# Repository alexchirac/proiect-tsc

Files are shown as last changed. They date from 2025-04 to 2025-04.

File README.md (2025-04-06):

## © Copyright Chirac Alexandru-Stefan 333CA

# Hardware Overview and Component Specifications

This document outlines the key hardware components used in the system, including their roles and detailed specifications.

---

## 📑 Table of Contents

- [Main Controller](#main-controller)
- [Display System](#display-system)
- [Power](#power)
- [Memory and Storage](#memory-and-storage)
- [Sensors](#sensors)
- [Connectivity](#connectivity)
- [Block diagram](#block-diagram)
- [Pin Assignments](#pin-assignments)
- [Bill of Materials](#bill-of-materials)

---

## Main Controller

### ESP32-C6-WROOM-1-N8
- **Function**: Core microcontroller that manages all system operations.

---

## Display System

### E-Paper Display
- **Drive Circuit**: Custom electronics for controlling the display.
- **Display Type Selector**: Configurable support for different e-paper types.

---

## Power

### LDO Voltage Regulator — XC6220A331MR-G
- **Function**: Supplies regulated 3.3V to the system.
- **Input Voltage**: Up to 6.0 V
- **Output Current**: Up to 700 mA

### Battery Charger — MCP73831
- **Function**: Manages Li-Po battery charging.
- **Charge Current**: Up to 500 mA (programmable)
- **Charge Voltage**: Fixed at 4.2 V
- **Input Voltage**: Typically 5 V (USB)
- **Features**: Thermal protection, automatic termination, LED status indicator

### Battery Fuel Gauge — MAX17048G+T10
- **Function**: Monitors battery state-of-charge and voltage.
- **Interface**: I2C
- **Voltage Accuracy**: ±7.5 mV
- **Current Consumption**: ~23 µA

### Supercapacitor — CPH3225A
- **Function**: Provides short-term backup power during power loss.

### Diode — MBR0530
- **Function**: Reverse voltage protection and efficient switching.
- **Max Current**: 0.5 A
- **Forward Voltage**: ~0.3–0.4 V

---

## Memory and Storage

### External NOR Flash — W25Q512JVEIQ
- **Function**: High-capacity external storage.
- **Capacity**: 512 Mbit (64 MB)
- **Interface**: SPI
- **Voltage**: 3.3 V
- **Usage**: Firmware, configuration data, graphical assets

### SD Card Slot
- **Function**: Expandable storage option for user or application data.

---

## Sensors

### Environmental Sensor — BME688
- **Function**: Measures environmental data.
- **Measurements**: Temperature, Humidity, Pressure, VOC gas
- **Interface**: I2C
- **Operating Voltage**: 1.7 V – 3.6 V

### RTC Module — DS3231SN
- **Function**: Maintains accurate timekeeping.
- **Accuracy**: ±2 ppm (~1 minute/year)
- **Interface**: I2C
- **Voltage**: 2.3 V – 5.5 V
- **Feature**: Integrated battery backup

---

## Connectivity

### USB-C Connector
- **Function**: Provides both power input and data communication.

### ESD Protection — USBLC6-2SC6Y
- **Function**: Protects USB lines from electrostatic discharge.

### Qwiic/Stemma QT Connector
- **Function**: Supports I2C-based expansion modules.

---

## Block Diagram

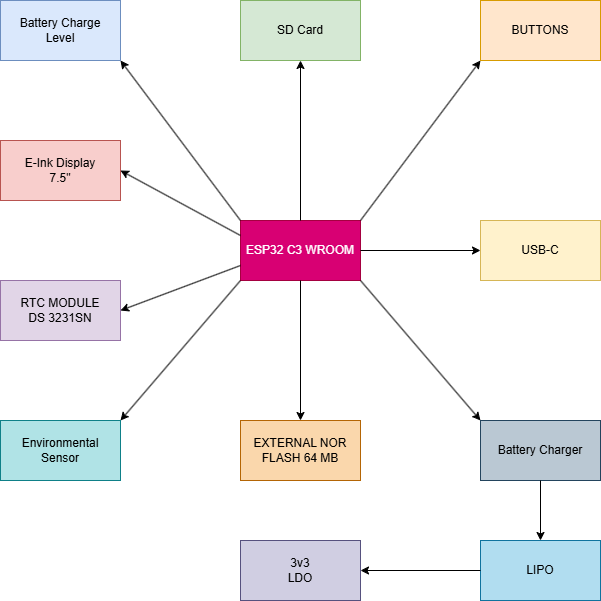
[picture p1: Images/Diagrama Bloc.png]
Block Diagram


---

## Pin Assignments

| ESP32-C6 Pin | Function | Connected To | Description |
|---|---|---|---|
| 3 | RESET | Reset Button | System hardware reset |
| 4 | SS_SD | SD Card (pin 2) | SPI Slave Select for SD card |
| 6 | SCK | SD Card (pin 5) | SPI Clock signal |
| 7 | MOSI | SD Card (pin 3) | SPI Master Out Slave In |
| 8 | INT_RTC | RTC Module (pin 3) | Interrupt signal from RTC |
| 9 | 32KHz | RTC Module (pin 1) | 32KHz clock signal from RTC |
| 13 | USB_D- | USB-C Connector (pin 3) | USB Data Negative line |
| 14 | USB_D+ | USB-C Connector (pin 1) | USB Data Positive line |
| 15 | IO/BOOT | Boot Button | Boot mode selector button |
| 16 | RTC_RST | RTC Module (pin 4) | RTC reset control |
| 17 | I2C_PW | BME688 Sensor (pins 6, 8, 2)| Power control for environmental sensor|
| 19 | SDA | Multiple I²C devices | I²C Serial Data line (shared) |
| 20 | SCL | Multiple I²C devices | I²C Serial Clock line (shared) |
| 23 | IO/CHANGE | Change Button | Display/Mode change button |
| 27 | MISO | SD Card (pin 7) | SPI Master In Slave Out |

---

## Bill of Materials

 | Device | Qty | PURCHASE-URL |
 |--------|-----|--------------|
 | ADAFRUIT_LEDCHIP-LED0603 | 1 | https://www.snapeda.com/parts/KP-1608SURCK/Kingbright/view-part/?ref=search&t=LED%200603 | 
 | EAGLE-LTSPICE_CC0402 | 1 | https://componentsearchengine.com/part-view/CC0402MRX5R5BB106/YAGEO | 
 | RCL_CPOL-EUCT3528 | 1 | https://a360.co/4iZy6AA | 
 | SJ | 1 | https://grabcad.com/library/solder-jumpers-1 | 
 | VARISTOR_3216 | 1 | https://www.mouser.co.uk/ProductDetail/EPCOS-TDK/B72520T0350K062?qs=dEfas%2FXlABIszF52uu7vrg%3D%3D | 
 | EAGLE-LTSPICE_CC0402 | 1 | https://componentsearchengine.com/part-view/CC0402MRX5R5BB106/YAGEO | 
 | ESP32_WROVER_EAGLE-LTSPICE_RR0402 | 1 | https://componentsearchengine.com/part-view/R0402%201%25%20100%20K%20(RC0402FR-07100KL)/YAGEO | 
 | EAGLE-LTSPICE_CC0402 | 1 | https://componentsearchengine.com/part-view/CC0402MRX5R5BB106/YAGEO | 
 | ESP32_WROVER_EAGLE-LTSPICE_RR0402 | 1 | https://componentsearchengine.com/part-view/R0402%201%25%20100%20K%20(RC0402FR-07100KL)/YAGEO | 
 | EAGLE-LTSPICE_CC0402 | 7 | https://componentsearchengine.com/part-view/CC0402MRX5R5BB106/YAGEO | 
 | ESP32_WROVER_EAGLE-LTSPICE_RR0402 | 16 | https://componentsearchengine.com/part-view/R0402%201%%20100%20K%20(RC0402FR-07100KL)/YAGEO | 
 | EAGLE-LTSPICE_CC0402 | 1 | https://componentsearchengine.com/part-view/CC0402MRX5R5BB106/YAGEO | 
 | 112A-TAAR-R03_ATTEND | 1 | https://store.comet.srl.ro/Catalogue/Product/43497/ | 
 | ESP32_WROVER_EAGLE-LTSPICE_RR0402 | 1 | https://componentsearchengine.com/part-view/R0402%201%25%20100%20K%20(RC0402FR-07100KL)/YAGEO | 
 | EAGLE-LTSPICE_CC0402 | 1 | https://componentsearchengine.com/part-view/CC0402MRX5R5BB106/YAGEO | 
 | EAGLE-LTSPICE_CC0402 | 8 | https://componentsearchengine.com/part-view/CC0402MRX5R5BB106/YAGEO | 
 | EAGLE-LTSPICE_CC0402 | 1 | https://componentsearchengine.com/part-view/CC0402MRX5R5BB106/YAGEO | 
 | ESP32_WROVER_EAGLE-LTSPICE_RR0402 | 1 | https://componentsearchengine.com/part-view/R0402%201%25%20100%20K%20(RC0402FR-07100KL)/YAGEO | 
 | ESP32_WROVER_EAGLE-LTSPICE_RR0402 | 1 | https://componentsearchengine.com/part-view/R0402%201%25%20100%20K%20(RC0402FR-07100KL)/YAGEO | 
 | ESP32_WROVER_SPARKFUN-DISCRETESEMI_MOSFET_PCH-DMG2305UX-7 | 2 | https://componentsearchengine.com/part-view/SI1308EDL-T1-GE3/Vishay | 
 | ESP32_WROVER_EAGLE-LTSPICE_RR0402 | 1 | https://componentsearchengine.com/part-view/R0402%201%25%20100%20K%20(RC0402FR-07100KL)/YAGEO | 
 | EAGLE-LTSPICE_CC0402 | 1 | https://componentsearchengine.com/part-view/CC0402MRX5R5BB106/YAGEO | 
 | EAGLE-LTSPICE_CC0402 | 3 | https://componentsearchengine.com/part-view/CC0402MRX5R5BB106/YAGEO | 
 | EAGLE-LTSPICE_CC0402 | 1 | https://componentsearchengine.com/part-view/CC0402MRX5R5BB106/YAGEO | 
 | ESP32_WROVER_EAGLE-LTSPICE_RR0402 | 2 | https://componentsearchengine.com/part-view/R0402%201%25%20100%20K%20(RC0402FR-07100KL)/YAGEO | 
 | 744043680IND_4828-WE-TPC_WRE | 1 | https://eu.mouser.com/ProductDetail/Wurth-Elektronik/744043680?qs=PGXP4M47uW6VkZq%252BkzjrHA%3D%3D | 
 | BD5229G-TR | 1 | https://componentsearchengine.com/part-view/BD5229G-TR/ROHM%20Semiconductor | 
 | BUTTON_CUSYOMV1PACKAGE | 3 | https://www.snapeda.com/parts/EVQP7L01P/Panasonic/view-part/?ref=search&t=evqp7l | 
 | CPH3225A | 1 | https://www.snapeda.com/api/url_track_click_mouser/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 | 
 | DS3231SN# | 1 | https://www.snapeda.com/api/url_track_click_mouser/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 | 
 | ESP32-C6-WROOM-1-N8 | 1 | https://www.snapeda.com/parts/ESP32-C6-WROOM-1-N8/Espressif+Systems/view-part/?ref=eda | 
 | ESP32_WROVER_AVX---SD0805S020S1R0_AVX_ SD0805S020S1R0_0_0AVX_SD0805S020S1R0_0_0 | 2 | https://eu.mouser.com/ProductDetail/KYOCERA-AVX/SD0805S020S1R0?qs=jCA%252BPfw4LHbpkAoSnwrdjw%3D%3D | 
 | ESP32_WROVER_BME680_BME680 | 1 | https://www.snapeda.com/parts/BME680/Bosch/view-part/?welcome=home | 
 | ESP32_WROVER_SPARKFUN-IC-POWER_MCP73831 | 1 | https://www.digikey.ro/en/products/detail/microchip-technology/MCP73831T-2ACI-OT/964301 | 
 | FH34SRJ-24S-0.5SH_99_ | 1 | https://componentsearchengine.com/part-view/XC6220A331MR-G/Torex | 
 | MAX17048G+T10 | 1 | https://www.snapeda.com/api/url_track_click_mouser/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 | 
 | MBR0530 | 3 | https://www.snapeda.com/api/url_track_click_mouser/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 | 
 | PGB1010603MR | 6 | https://www.snapeda.com/api/url_track_click_mouser/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 | 
 | QWIIC_CONNECTORJS-1MM | 1 | https://www.digikey.ro/en/models/926710 | 
 | SAMACSYS_PARTS_USB4110-GF-A | 1 | https://componentsearchengine.com/part-view/USB4110-GF-A/GCT%20(GLOBAL%20CONNECTOR%20TECHNOLOGY) | 
 | SI1308EDL-T1-GE3 | 1 | https://componentsearchengine.com/part-view/SI1308EDL-T1-GE3/Vishay | 
 | TPTP20R | 17 | https://grabcad.com/library/test-points-printed-circuit-board-1 | 
 | USBLC6-2SC6Y | 1 | https://www.snapeda.com/parts/USBLC6-2SC6Y/STMicroelectronics/view-part/?ref=eda | 
 | W25Q512JVEIQ | 1 | https://www.snapeda.com/parts/W25Q512JVEIQ/Winbond+Electronics/view-part/?ref=eda |

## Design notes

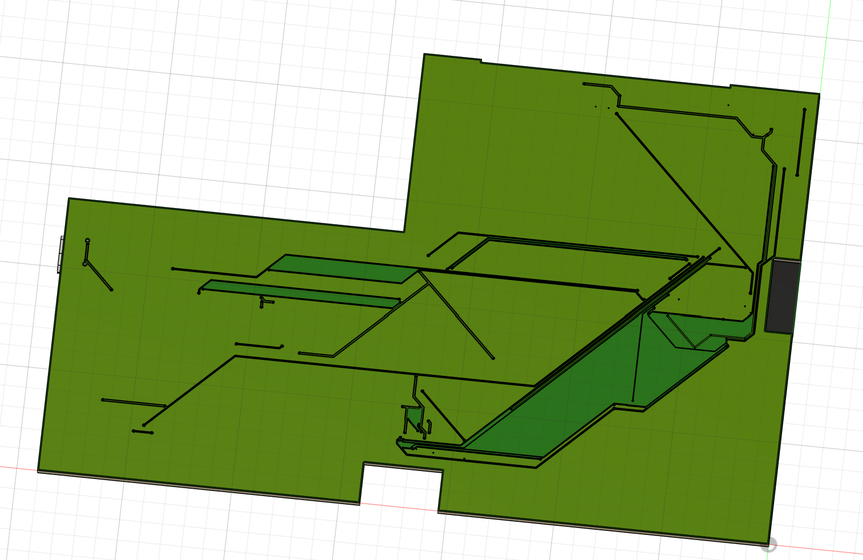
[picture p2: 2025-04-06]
Images/Board Back.png

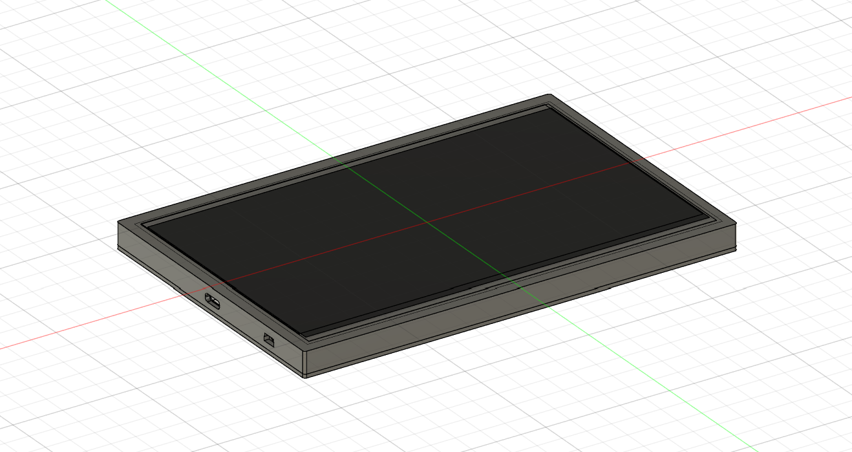
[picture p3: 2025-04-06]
Images/Device Top.png

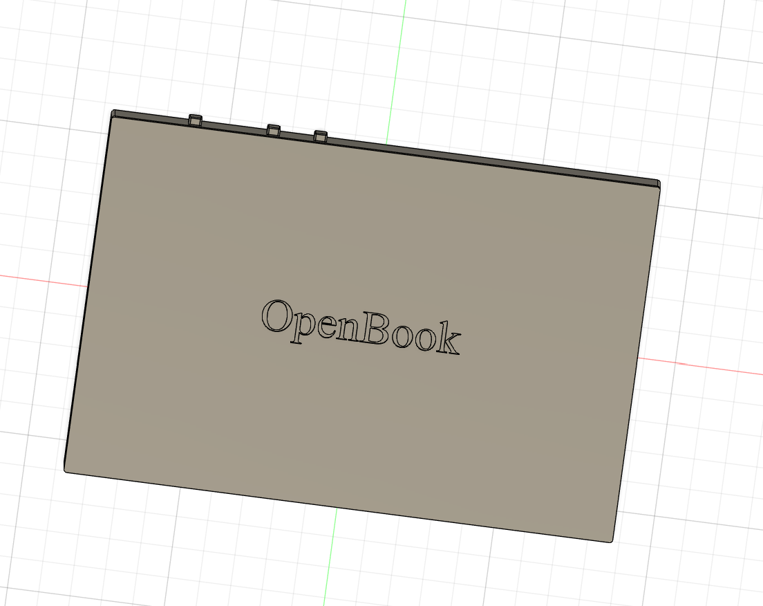
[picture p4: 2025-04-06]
Images/Device Back.png

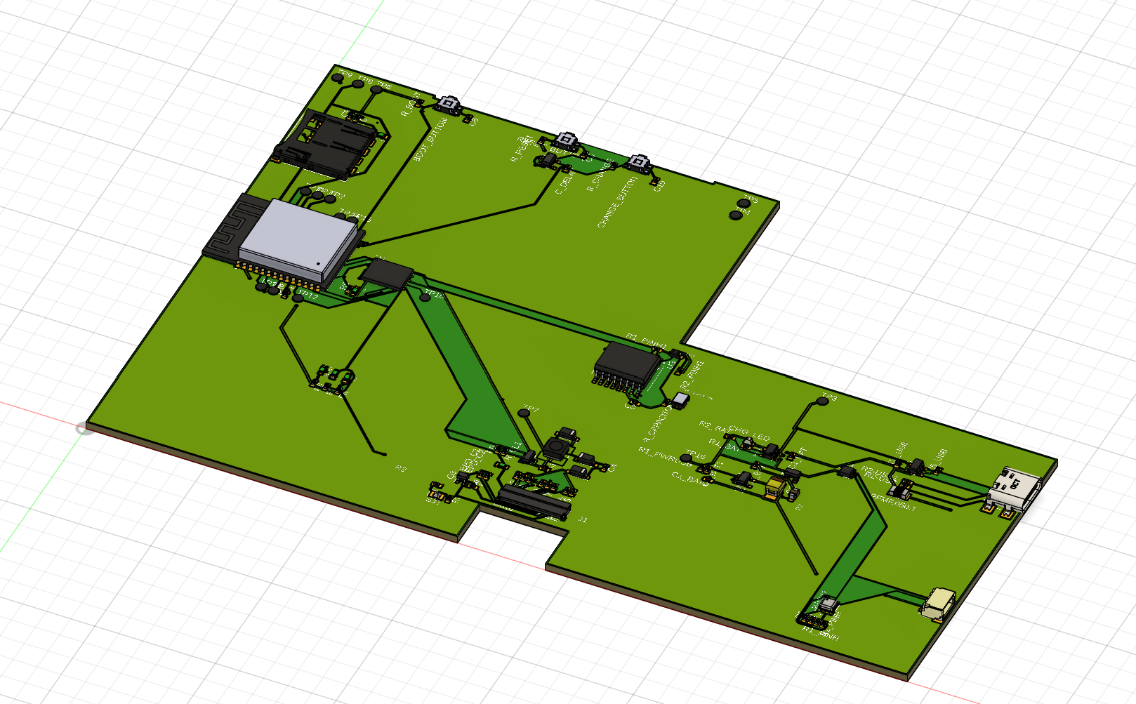
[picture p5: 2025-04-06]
Images/Board Top.png

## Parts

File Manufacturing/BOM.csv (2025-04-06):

Qty | Value | Device | Package | Parts | Description | ARROW_PART_NUMBER | ARROW_PRICE-STOCK | AVAILABILITY | BREAKDOWN_VOLTAGE | CATEGORY | CENTROID_NOT_SPECIFIED | CHECK_PRICES | CLAMPING_VOLTAGE | COPYRIGHT | CURRENT_RATING | CURRENT_SURGE | DATASHEET | DESCRIPTION | DIGIKEY_DESCRIPTION | DIGIKEY_PART_NUMBER | HEIGHT | LEAD_FREE | MANUFACTURER | MANUFACTURER_NAME | MANUFACTURER_PART_NUMBER | MF | MFR_NAME | MOUSER_PART_NUMBER | MOUSER_PRICE-STOCK | MOUSER_TESTING_PART_NUMBER | MOUSER_TESTING_PRICE-STOCK | MP | MPN | OPERATING_TEMPERATURE | PACKAGE | PACKAGE_SIZE | PACKAGE_TYPE | PART_STATUS | POPULARITY | PREFIX | PRICE | PROD_ID | PURCHASE-URL | ROHS | SERIES | SNAPEDA_LINK | SPICEMODEL | SPICEPREFIX | SUBCATEGORY | TEMPERATURE_RANGE_HIGH | TEMPERATURE_RANGE_LOW | THERMALLOSS | TP_SIGNAL_NAME | TYPE | VALUE | VARISTOR_VOLTAGE | VOLTAGE_RATING
1 |  | ADAFRUIT_LEDCHIP-LED0603 | ADAFRUIT_CHIP-LED0603 | CHG_LED | LED |  |  |  |  |  |  |  |  |  |  |  |  |  |  |  |  |  |  |  |  |  |  |  |  |  |  |  |  |  |  |  |  |  |  |  |  |  | https://www.snapeda.com/parts/KP-1608SURCK/Kingbright/view-part/?ref=search&t=LED%200603
1 |  | EAGLE-LTSPICE_CC0402 | EAGLE-LTSPICE_C0402 | C1_BAT1 | CAPACITOR, European symbol |  |  |  |  |  |  |  |  |  |  |  |  |  |  |  |  |  |  |  |  |  |  |  |  |  |  |  |  |  |  |  |  |  |  |  |  |  | https://componentsearchengine.com/part-view/CC0402MRX5R5BB106/YAGEO |  |  |  | NONE | C
1 |  | RCL_CPOL-EUCT3528 | RCL_CT3528 | C3 | POLARIZED CAPACITOR, European symbol |  |  |  |  |  |  |  |  |  |  |  |  |  |  |  |  |  |  |  |  |  |  |  |  |  |  |  |  |  |  |  |  |  | 0 |  |  |  | https://a360.co/4iZy6AA |  |  |  |  | C
1 |  | SJ | SJ | SJ1 | SMD solder JUMPER |  |  |  |  |  |  |  |  |  |  |  |  |  |  |  |  |  |  |  |  |  |  |  |  |  |  |  |  |  |  |  |  |  | 3 |  |  |  | https://grabcad.com/library/solder-jumpers-1
1 |  | VARISTOR_3216 | VARC3216X102N | PFMF.050.1 | Varistor - Generic |  |  |  |  | Circuit-Protection |  |  |  |  |  |  |  |  |  |  |  |  |  |  |  |  |  |  |  |  |  |  |  |  |  | 1206 | SMD |  |  |  |  |  | https://www.mouser.co.uk/ProductDetail/EPCOS-TDK/B72520T0350K062?qs=dEfas%2FXlABIszF52uu7vrg%3D%3D |  |  |  |  |  | Varistor
1 | 0.1uF/50V | EAGLE-LTSPICE_CC0402 | EAGLE-LTSPICE_C0402 | EPD_C5 | CAPACITOR, European symbol |  |  |  |  |  |  |  |  |  |  |  |  |  |  |  |  |  |  |  |  |  |  |  |  |  |  |  |  |  |  |  |  |  |  |  |  |  | https://componentsearchengine.com/part-view/CC0402MRX5R5BB106/YAGEO |  |  |  | NONE | C
1 | 0.47 | ESP32_WROVER_EAGLE-LTSPICE_RR0402 | ESP32_WROVER_EAGLE-LTSPICE_R0402 | R3 | RESISTOR, European symbol |  |  |  |  |  |  |  |  |  |  |  |  |  |  |  |  |  |  |  |  |  |  |  |  |  |  |  |  |  |  |  |  |  |  |  |  |  | https://componentsearchengine.com/part-view/R0402%201%25%20100%20K%20(RC0402FR-07100KL)/YAGEO |  |  |  | NONE | R
1 | 100 nF | EAGLE-LTSPICE_CC0402 | EAGLE-LTSPICE_C0402 | C4_USB | CAPACITOR, European symbol |  |  |  |  |  |  |  |  |  |  |  |  |  |  |  |  |  |  |  |  |  |  |  |  |  |  |  |  |  |  |  |  |  |  |  |  |  | https://componentsearchengine.com/part-view/CC0402MRX5R5BB106/YAGEO |  |  |  | NONE | C
1 | 100K | ESP32_WROVER_EAGLE-LTSPICE_RR0402 | ESP32_WROVER_EAGLE-LTSPICE_R0402 | R1_PWRUSB | RESISTOR, European symbol |  |  |  |  |  |  |  |  |  |  |  |  |  |  |  |  |  |  |  |  |  |  |  |  |  |  |  |  |  |  |  |  |  |  |  |  |  | https://componentsearchengine.com/part-view/R0402%201%25%20100%20K%20(RC0402FR-07100KL)/YAGEO |  |  |  | NONE | R
7 | 100nF | EAGLE-LTSPICE_CC0402 | EAGLE-LTSPICE_C0402 | C1, C2, C6, C8, C9, C10, C_DELAY | CAPACITOR, European symbol |  |  |  |  |  |  |  |  |  |  |  |  |  |  |  |  |  |  |  |  |  |  |  |  |  |  |  |  |  |  |  |  |  |  |  |  |  | https://componentsearchengine.com/part-view/CC0402MRX5R5BB106/YAGEO |  |  |  | NONE | C
16 | 10K | ESP32_WROVER_EAGLE-LTSPICE_RR0402 | ESP32_WROVER_EAGLE-LTSPICE_R0402 | R1, R1_PINH, R1_PINH1, R2_PINH, R2_PINH1, R4, R5, R6, R7, R8, R9, R10, R_BOOT, R_CHANGE, R_CL1, R_RESET | RESISTOR, European symbol |  |  |  |  |  |  |  |  |  |  |  |  |  |  |  |  |  |  |  |  |  |  |  |  |  |  |  |  |  |  |  |  |  |  |  |  |  | https://componentsearchengine.com/part-view/R0402 1% 100 K (RC0402FR-07100KL)/YAGEO |  |  |  | NONE | R
1 | 10uF | EAGLE-LTSPICE_CC0402 | EAGLE-LTSPICE_C0402 | C7 | CAPACITOR, European symbol |  |  |  |  |  |  |  |  |  |  |  |  |  |  |  |  |  |  |  |  |  |  |  |  |  |  |  |  |  |  |  |  |  |  |  |  |  | https://componentsearchengine.com/part-view/CC0402MRX5R5BB106/YAGEO |  |  |  | NONE | C
1 | 112A-TAAR-R03_ATTEND | 112A-TAAR-R03_ATTEND | 112ATAARR03ATTEND | J4 | Micro SD Card Socket, Push-Push Type, Top Mount, SMT, H=1.83mm, 10u |  |  |  |  |  |  |  |  |  |  |  |  | Micro SD Card Socket | Push-Push Type | Top Mount | SMT | H=1.83mm | 10u |  |  | 1.9mm |  |  | ATTEND | 112A-TAAR-R03 ATTEND |  |  |  |  |  |  |  |  |  |  |  |  | https://store.comet.srl.ro/Catalogue/Product/43497/
1 | 15 | ESP32_WROVER_EAGLE-LTSPICE_RR0402 | ESP32_WROVER_EAGLE-LTSPICE_R0402 | R_CAPACITOR | RESISTOR, European symbol |  |  |  |  |  |  |  |  |  |  |  |  |  |  |  |  |  |  |  |  |  |  |  |  |  |  |  |  |  |  |  |  |  |  |  |  |  | https://componentsearchengine.com/part-view/R0402%201%25%20100%20K%20(RC0402FR-07100KL)/YAGEO |  |  |  | NONE | R
1 | 1uF | EAGLE-LTSPICE_CC0402 | EAGLE-LTSPICE_C0402 | C5 | CAPACITOR, European symbol |  |  |  |  |  |  |  |  |  |  |  |  |  |  |  |  |  |  |  |  |  |  |  |  |  |  |  |  |  |  |  |  |  |  |  |  |  | https://componentsearchengine.com/part-view/CC0402MRX5R5BB106/YAGEO |  |  |  | NONE | C
8 | 1uF/50V | EAGLE-LTSPICE_CC0402 | EAGLE-LTSPICE_C0402 | EPD_C1, EPD_C2, EPD_C6, EPD_C8, EPD_C9, EPD_C10, EPD_C11, EPD_C12 | CAPACITOR, European symbol |  |  |  |  |  |  |  |  |  |  |  |  |  |  |  |  |  |  |  |  |  |  |  |  |  |  |  |  |  |  |  |  |  |  |  |  |  | https://componentsearchengine.com/part-view/CC0402MRX5R5BB106/YAGEO |  |  |  | NONE | C
1 | 1uf/50V | EAGLE-LTSPICE_CC0402 | EAGLE-LTSPICE_C0402 | EPD_C7 | CAPACITOR, European symbol |  |  |  |  |  |  |  |  |  |  |  |  |  |  |  |  |  |  |  |  |  |  |  |  |  |  |  |  |  |  |  |  |  |  |  |  |  | https://componentsearchengine.com/part-view/CC0402MRX5R5BB106/YAGEO |  |  |  | NONE | C
1 | 2.2 | ESP32_WROVER_EAGLE-LTSPICE_RR0402 | ESP32_WROVER_EAGLE-LTSPICE_R0402 | R2 | RESISTOR, European symbol |  |  |  |  |  |  |  |  |  |  |  |  |  |  |  |  |  |  |  |  |  |  |  |  |  |  |  |  |  |  |  |  |  |  |  |  |  | https://componentsearchengine.com/part-view/R0402%201%25%20100%20K%20(RC0402FR-07100KL)/YAGEO |  |  |  | NONE | R
1 | 200 | ESP32_WROVER_EAGLE-LTSPICE_RR0402 | ESP32_WROVER_EAGLE-LTSPICE_R0402 | R1_BAT | RESISTOR, European symbol |  |  |  |  |  |  |  |  |  |  |  |  |  |  |  |  |  |  |  |  |  |  |  |  |  |  |  |  |  |  |  |  |  |  |  |  |  | https://componentsearchengine.com/part-view/R0402%201%25%20100%20K%20(RC0402FR-07100KL)/YAGEO |  |  |  | NONE | R
2 | 20V/4.2A/52mO/1.4W | ESP32_WROVER_SPARKFUN-DISCRETESEMI_MOSFET_PCH-DMG2305UX-7 | ESP32_WROVER_SPARKFUN-DISCRETESEMI_SOT23-3 | Q1, Q2 | P-channel MOSFETs |  |  |  |  |  |  |  |  |  |  |  |  |  |  |  |  |  |  |  |  |  |  |  |  |  |  |  |  |  |  |  |  |  |  |  |  | TRAN-14388 | https://componentsearchengine.com/part-view/SI1308EDL-T1-GE3/Vishay |  |  |  |  |  |  |  |  |  |  |  | 20V/4.2A/52mO/1.4W
1 | 2K | ESP32_WROVER_EAGLE-LTSPICE_RR0402 | ESP32_WROVER_EAGLE-LTSPICE_R0402 | R2_BAT | RESISTOR, European symbol |  |  |  |  |  |  |  |  |  |  |  |  |  |  |  |  |  |  |  |  |  |  |  |  |  |  |  |  |  |  |  |  |  |  |  |  |  | https://componentsearchengine.com/part-view/R0402%201%25%20100%20K%20(RC0402FR-07100KL)/YAGEO |  |  |  | NONE | R
1 | 4.7 uF | EAGLE-LTSPICE_CC0402 | EAGLE-LTSPICE_C0402 | C5_USB | CAPACITOR, European symbol |  |  |  |  |  |  |  |  |  |  |  |  |  |  |  |  |  |  |  |  |  |  |  |  |  |  |  |  |  |  |  |  |  |  |  |  |  | https://componentsearchengine.com/part-view/CC0402MRX5R5BB106/YAGEO |  |  |  | NONE | C
3 | 4.7uF | EAGLE-LTSPICE_CC0402 | EAGLE-LTSPICE_C0402 | C1_BAT, C1_BAT2, C2_BAT | CAPACITOR, European symbol |  |  |  |  |  |  |  |  |  |  |  |  |  |  |  |  |  |  |  |  |  |  |  |  |  |  |  |  |  |  |  |  |  |  |  |  |  | https://componentsearchengine.com/part-view/CC0402MRX5R5BB106/YAGEO |  |  |  | NONE | C
1 | 4.7uF/25V | EAGLE-LTSPICE_CC0402 | EAGLE-LTSPICE_C0402 | C4 | CAPACITOR, European symbol |  |  |  |  |  |  |  |  |  |  |  |  |  |  |  |  |  |  |  |  |  |  |  |  |  |  |  |  |  |  |  |  |  |  |  |  |  | https://componentsearchengine.com/part-view/CC0402MRX5R5BB106/YAGEO |  |  |  | NONE | C
2 | 5k1 | ESP32_WROVER_EAGLE-LTSPICE_RR0402 | ESP32_WROVER_EAGLE-LTSPICE_R0402 | R2-USB, R2-USB1 | RESISTOR, European symbol |  |  |  |  |  |  |  |  |  |  |  |  |  |  |  |  |  |  |  |  |  |  |  |  |  |  |  |  |  |  |  |  |  |  |  |  |  | https://componentsearchengine.com/part-view/R0402%201%25%20100%20K%20(RC0402FR-07100KL)/YAGEO |  |  |  | NONE | R
1 | 744043680IND_4828-WE-TPC_WRE | 744043680IND_4828-WE-TPC_WRE | IND_4828-WE-TPC_WRE | L1 |  |  |  |  |  |  |  |  |  | Copyright (C) 2024 Ultra Librarian. All rights reserved. |  |  |  |  |  |  |  |  |  |  | 744043680 |  | Wurth Electronics |  |  |  |  |  |  |  |  |  |  |  |  |  |  |  | https://eu.mouser.com/ProductDetail/Wurth-Elektronik/744043680?qs=PGXP4M47uW6VkZq%252BkzjrHA%3D%3D
1 | BD5229G-TR | BD5229G-TR | SOT95P280X125-5N | IC1 | Voltage Detector with Adjustable Delay Time: CMOS processes are utilized to develop high precision, low current consumption CMOS reset ICs that allow arbitrary setting of the delay time. The extensive lineup includes both Nch Open Drain and CMOS output types in a wide range of detection voltages (from 2.3V to 6.0V, in 0.1V steps), enabling selection of the ideal solution based on customer requirements. In addition, the entire series is of course both lead-free and RoHS-compliant. |  |  |  |  |  |  |  |  |  |  |  |  | Voltage Detector with Adjustable Delay Time: CMOS processes are utilized to develop high precision | low current consumption CMOS reset ICs that allow arbitrary setting of the delay time. The extensive lineup includes both Nch Open Drain and CMOS output types in a wide range of detection voltages (from 2.3V to 6.0V | in 0.1V steps) | enabling selection of the ideal solution based on customer requirements. In addition | the entire series is of course both lead-free and RoHS-compliant. |  |  | 1.25mm |  |  | ROHM Semiconductor | BD5229G-TR |  |  | 755-BD5229G-TR | https://www.mouser.co.uk/ProductDetail/ROHM-Semiconductor/BD5229G-TR?qs=4kLU8WoGk0vvnhrrYwdszw%3D%3D |  |  |  |  |  |  |  |  |  | https://componentsearchengine.com/part-view/BD5229G-TR/ROHM%20Semiconductor
3 | BUTTON_CUSYOMV1PACKAGE | BUTTON_CUSYOMV1PACKAGE | MYBUTTON | BOOT_BUTTON, CHANGE_BUTTON, RESET_BUTTON |  |  |  |  |  |  |  |  |  |  |  |  |  |  |  |  |  |  |  |  |  |  |  |  |  |  |  |  |  |  |  |  |  |  |  |  |  |  | https://www.snapeda.com/parts/EVQP7L01P/Panasonic/view-part/?ref=search&t=evqp7l
1 | CPH3225A | CPH3225A | CAPCP3225X100N | C10_SUPERCAP | Cap 0.011F 3.3V 1210 Flat Check availability |  |  | Not in stock |  |  |  | https://www.snapeda.com/parts/CPH3225A/Seiko+Instruments/view-part/?ref=eda |  |  |  |  |  | 11 mF (EDLC) Supercapacitor 3.3 V 1210 (3225 Metric) - - |  |  |  |  |  |  |  | Seiko Instruments |  |  |  |  |  | CPH3225A |  |  | 1210 Seiko |  |  |  |  |  | None |  | https://www.snapeda.com/api/url_track_click_mouser/?unipart_id=562593&manufacturer=Seiko Instruments&part_name=CPH3225A&search_term=None |  |  | https://www.snapeda.com/parts/CPH3225A/Seiko+Instruments/view-part/?ref=snap
1 | DS3231SN# | DS3231SN# | SOIC127P1032X265-16N | U3 | Real Time Clock Serial 16-Pin SOIC W T/R Check availability |  |  | In Stock |  |  |  | https://www.snapeda.com/parts/DS3231SN%23/Analog+Devices/view-part/?ref=eda |  |  |  |  |  | Extremely Accurate I²C-Integrated RTC/TCXO/Crystal |  |  |  |  |  |  |  | Analog Devices |  |  |  |  |  | DS3231SN# |  |  | SOIC-16 Maxim |  |  |  |  |  | None |  | https://www.snapeda.com/api/url_track_click_mouser/?unipart_id=99048&manufacturer=Analog Devices&part_name=DS3231SN#&search_term=None |  |  | https://www.snapeda.com/parts/DS3231SN%23/Analog+Devices/view-part/?ref=snap
1 | ESP32-C6-WROOM-1-N8 | ESP32-C6-WROOM-1-N8 | XCVR_ESP32-C6-WROOM-1-N8 | U2 | Check availability |  |  | In Stock |  |  |  | https://www.snapeda.com/parts/ESP32-C6-WROOM-1-N8/Espressif+Systems/view-part/?ref=eda |  |  |  |  |  | Multiprotocol Modules ESP32-C6 module | Wi-Fi 6 in 2.4 GHz band | Bluetooth 5 | Zigbee 3.0 and Thread. ESP34-WROOM Compatible - ENGINEERING SAMPLE |  |  |  |  |  |  |  | Espressif Systems |  |  |  |  |  | ESP32-C6-WROOM-1-N8 |  |  | None |  |  |  |  | https://www.snapeda.com/parts/ESP32-C6-WROOM-1-N8/Espressif+Systems/view-part/?ref=eda | None |  |  |  |  | https://www.snapeda.com/parts/ESP32-C6-WROOM-1-N8/Espressif+Systems/view-part/?ref=snap
2 | ESP32_WROVER_AVX---SD0805S020S1R0_AVX_SD0805S020S1R0_0_0AVX_SD0805S020S1R0_0_0 | ESP32_WROVER_AVX---SD0805S020S1R0_AVX_SD0805S020S1R0_0_0AVX_SD0805S020S1R0_0_0 | ESP32_WROVER_AVX---SD0805S020S1R0_AVX_SD0805S020S1R0_0 | D2, D7 | Schottky Barrier Rectifier Diode |  |  |  |  |  | No |  |  |  |  |  | http://datasheets.avx.com/schottky.pdf |  | DIODE SCHOTTKY 20V 1A 0805 | 478-7800-1-ND |  | yes |  |  |  | AVX |  | 581-SD0805S020S1R0 |  |  |  |  |  |  | 0805 (2012 metric) |  |  |  |  | D |  |  | https://eu.mouser.com/ProductDetail/KYOCERA-AVX/SD0805S020S1R0?qs=jCA%252BPfw4LHbpkAoSnwrdjw%3D%3D | yes |  |  |  |  |  | +125°C | -55°C
1 | ESP32_WROVER_BME680_BME680 | ESP32_WROVER_BME680_BME680 | ESP32_WROVER_BME680_PSON80P300X300X100-8N | SENSOR2 | Integrated Environmental Unit |  |  | Unavailable |  |  |  |  |  |  |  |  |  | Integrated Environmental Unit |  |  |  |  |  |  |  | Bosch Sensortec |  |  |  |  |  | BME680 |  |  | LGA-8 Bosch Tools |  |  |  |  |  | None |  | https://www.snapeda.com/parts/BME680/Bosch/view-part/?welcome=home
1 | ESP32_WROVER_SPARKFUN-IC-POWER_MCP73831 | ESP32_WROVER_SPARKFUN-IC-POWER_MCP73831 | ESP32_WROVER_SPARKFUN-IC-POWER_SOT23-5 | MCP73831 | MCP73831T Li-Ion, Li-Pol Controller |  |  |  |  |  |  |  |  |  |  |  |  |  |  |  |  |  |  |  |  |  |  |  |  |  |  |  |  |  |  |  |  |  |  |  |  | IC-09995 | https://www.digikey.ro/en/products/detail/microchip-technology/MCP73831T-2ACI-OT/964301
1 | FH34SRJ-24S-0.5SH_99_ | FH34SRJ-24S-0.5SH_99_ | FH34SRJ24S05SH99 | J1 | (0.50mm) Surface Mount, Right Angle |  |  |  |  |  |  |  |  |  |  |  |  | 24 Position FFC | FPC Connector Contacts | (0.50mm) Surface Mount | Right Angle |  |  | 1.1mm |  |  | Hirose | FH34SRJ-24S-0.5SH(99) |  |  | 798-FH34SRJ24S05SH99 | https://www.mouser.co.uk/ProductDetail/Hirose-Connector/FH34SRJ-24S-0.5SH99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 |  |  |  |  |  |  |  |  |  |  | https://componentsearchengine.com/part-view/XC6220A331MR-G/Torex
1 | MAX17048G+T10 | MAX17048G+T10 | SON50P200X200X80-9N | U4 | Check availability |  |  | In Stock |  |  |  | https://www.snapeda.com/parts/MAX17048G+T10/Analog+Devices/view-part/?ref=eda |  |  |  |  |  | 3µA 1-Cell/2-Cell Fuel Gauge with ModelGauge |  |  |  |  |  |  |  | Analog Devices |  |  |  |  |  | MAX17048G+T10 |  |  | TDFN-8 Maxim |  |  |  |  |  | None |  | https://www.snapeda.com/api/url_track_click_mouser/?unipart_id=329239&manufacturer=Analog Devices&part_name=MAX17048G+T10&search_term=None |  |  | https://www.snapeda.com/parts/MAX17048G+T10/Analog+Devices/view-part/?ref=snap
3 | MBR0530 | MBR0530 | SOD3716X135N | D3, D4, D5 | ON SEMICONDUCTOR - MBR0530 - DIODE, SCHOTTKY, 0.5A, 30V, SOD-123 |  |  | In Stock |  |  |  | https://www.snapeda.com/parts/MBR0530/Onsemi/view-part/?ref=eda |  |  |  |  |  | Diode Schottky 30 V 500mA Surface Mount SOD-123 |  |  |  |  |  |  |  | ON Semiconductor |  |  |  |  |  | MBR0530 |  |  | SOD-123-2 ON Semiconductor |  |  |  |  |  | None |  | https://www.snapeda.com/api/url_track_click_mouser/?unipart_id=179458&manufacturer=ON Semiconductor&part_name=MBR0530&search_term=None |  |  | https://www.snapeda.com/parts/MBR0530/Onsemi/view-part/?ref=snap
6 | PGB1010603MR | PGB1010603MR | DIOC1608X36N | D6, D8, D9, D10, D11, D12 | Check availability |  |  | In Stock |  |  |  | https://www.snapeda.com/parts/PGB1010603MR/Littelfuse/view-part/?ref=eda |  |  |  |  |  | 150V (Typ) Clamp - Ipp Tvs Diode Surface Mount 0603 (1608 Metric) |  |  |  |  |  |  |  | Littelfuse Inc. |  |  |  |  |  | PGB1010603MR |  |  | 0603 Littelfuse Inc. |  |  |  |  |  | None |  | https://www.snapeda.com/api/url_track_click_mouser/?unipart_id=5659453&manufacturer=Littelfuse Inc.&part_name=PGB1010603MR&search_term=None |  |  | https://www.snapeda.com/parts/PGB1010603MR/Littelfuse/view-part/?ref=snap
1 | QWIIC_RIGHT_ANGLE | QWIIC_CONNECTORJS-1MM | JST04_1MM_RA | J3 | SparkFun I2C Standard Qwiic Connector |  |  |  |  |  |  |  |  |  |  |  |  |  |  |  |  |  |  |  |  |  |  |  |  |  |  |  |  |  |  |  |  |  |  |  |  | CONN-13694 | https://www.digikey.ro/en/models/926710 |  |  |  |  |  |  |  |  |  |  |  | QWIIC_RIGHT_ANGLE
1 | SAMACSYS_PARTS_USB4110-GF-A | SAMACSYS_PARTS_USB4110-GF-A | SAMACSYS_PARTS_USB4110GFA | J2 | CONN USB 2.0 TYPE-C R/A SMT |  |  |  |  |  |  |  |  |  |  |  |  | CONN USB 2.0 TYPE-C R/A SMT |  |  | 3.26mm |  |  | GCT (GLOBAL CONNECTOR TECHNOLOGY) | USB4110-GF-A |  |  | 640-USB4110-GF-A | https://www.mouser.co.uk/ProductDetail/GCT/USB4110-GF-A?qs=KUoIvG%2F9IlYiZvIXQjyJeA%3D%3D |  |  |  |  |  |  |  |  |  |  |  |  |  | https://componentsearchengine.com/part-view/USB4110-GF-A/GCT%20(GLOBAL%20CONNECTOR%20TECHNOLOGY)
1 | SI1308EDL-T1-GE3 | SI1308EDL-T1-GE3 | SOT65P210X110-3N | Q3 | MOSFET N-Ch 30V 1.5A TrenchFET SC70 Vishay Si1308EDL-T1-GE3 N-channel MOSFET Transistor, 1.5 A, 30 V, 3-Pin SC-70 |  |  | In Stock |  |  |  | https://www.snapeda.com/parts/SI1308EDL-T1-GE3/Vishay+Siliconix/view-part/?ref=eda |  |  |  |  |  | Si1308EDL-T1-GE3 N-channel MOSFET Transistor | 1.5 A | 30 V | 3-Pin SC-70 | Siliconix / Vishay SI1308EDL-T1-GE3 |  |  |  |  |  |  |  | Vishay Siliconix |  |  |  |  |  | SI1308EDL-T1-GE3 |  |  | SOT-323 Vishay Semiconductor |  |  |  |  | https://componentsearchengine.com/part-view/SI1308EDL-T1-GE3/Vishay | None |  | https://www.snapeda.com/api/url_track_click_mouser/?unipart_id=274603&manufacturer=Vishay Siliconix&part_name=SI1308EDL-T1-GE3&search_term=None |  |  | https://www.snapeda.com/parts/SI1308EDL-T1-GE3/Vishay+Siliconix/view-part/?ref=snap
17 | TPTP20R | TPTP20R | TP20R | TP1, TP2, TP3, TP4, TP5, TP6, TP7, TP8, TP9, TP10, TP11, TP12, TP13, TP14, TP15, TP16, TP17 | Test pad |  |  |  |  |  |  |  |  |  |  |  |  |  |  |  |  |  |  |  |  |  |  |  |  |  |  |  |  |  |  |  |  |  | 2 |  |  |  | https://grabcad.com/library/test-points-printed-circuit-board-1
1 | USBLC6-2SC6Y | USBLC6-2SC6Y | SOT95P280X145-6N | D1 | Low Cap. ESD Protection Auto SOT-23-6 STMicroelectronics USBLC6-2SC6Y, Dual Uni-Directional TVS Diode Array, 6-Pin SOT-23 |  |  | In Stock |  |  |  | https://www.snapeda.com/parts/USBLC6-2SC6Y/STMicroelectronics/view-part/?ref=eda |  |  |  |  |  | 17V Clamp 5A (8/20µs) Ipp Tvs Diode Surface Mount SOT-23-6 |  |  |  |  |  |  |  | STMicroelectronics |  |  |  |  |  | USBLC6-2SC6Y |  |  | SOT-23-6 STMicroelectronics |  |  |  |  |  | None |  | https://www.snapeda.com/parts/USBLC6-2SC6Y/STMicroelectronics/view-part/?ref=eda |  |  | https://www.snapeda.com/parts/USBLC6-2SC6Y/STMicroelectronics/view-part/?ref=snap
1 | W25Q512JVEIQ | W25Q512JVEIQ | SON127P600X800X80-9N | U1 | Check availability |  |  | In Stock |  |  |  | https://www.snapeda.com/parts/W25Q512JVEIQ/Winbond+Electronics/view-part/?ref=eda |  |  |  |  |  | FLASH - NOR Memory IC 512Mb (64M x 8) SPI - Quad I/O 133 MHz 8-WSON (8x6) |  |  |  |  |  |  |  | Winbond Electronics |  |  |  |  |  | W25Q512JVEIQ |  |  | Package |  |  |  |  |  | None |  | https://www.snapeda.com/parts/W25Q512JVEIQ/Winbond+Electronics/view-part/?ref=eda |  |  | https://www.snapeda.com/parts/W25Q512JVEIQ/Winbond+Electronics/view-part/?ref=snap
1 | XC6220A331MR-G | XC6220A331MR-G | SOT95P280X120-5N | IC4 | LDO Voltage Regulators |  |  |  |  |  |  |  |  |  |  |  |  | LDO Voltage Regulators |  |  | 1.2mm |  |  | Torex | XC6220A331MR-G |  |  | 865-XC6220A331MR-G | https://www.mouser.co.uk/ProductDetail/Torex-Semiconductor/XC6220A331MR-G?qs=AsjdqWjXhJ8ZSWznL1J0gg%3D%3D |  |  |  |  |  |  |  |  |  |  |  |  |  | https://componentsearchengine.com/part-view/XC6220A331MR-G/Torex

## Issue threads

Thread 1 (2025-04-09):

No values

LepinzeanStefan, 2025-04-09:
Capacitors C3 an C1_BAT1 have no value assigned to them.

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

alexchirac, 2025-04-15:
Solved

Closed 2025-04-15.

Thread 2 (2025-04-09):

No via stitches

LepinzeanStefan, 2025-04-09:
There are no via stiches  between the two ground planes. You should add some, especially near the esp32 module. Here is how you can add one:

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

alexchirac, 2025-04-15:
Solved

Closed 2025-04-15.

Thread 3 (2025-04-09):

Silkscreen problems

LepinzeanStefan, 2025-04-09:
The silkscreen for the testpads should be named after the routes they are connected to, also you should space the text so it is easier to read on the silkscreen.  Some of them are overlaping each other. Here is an exemple of both problems:

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

Closed 2025-04-15.

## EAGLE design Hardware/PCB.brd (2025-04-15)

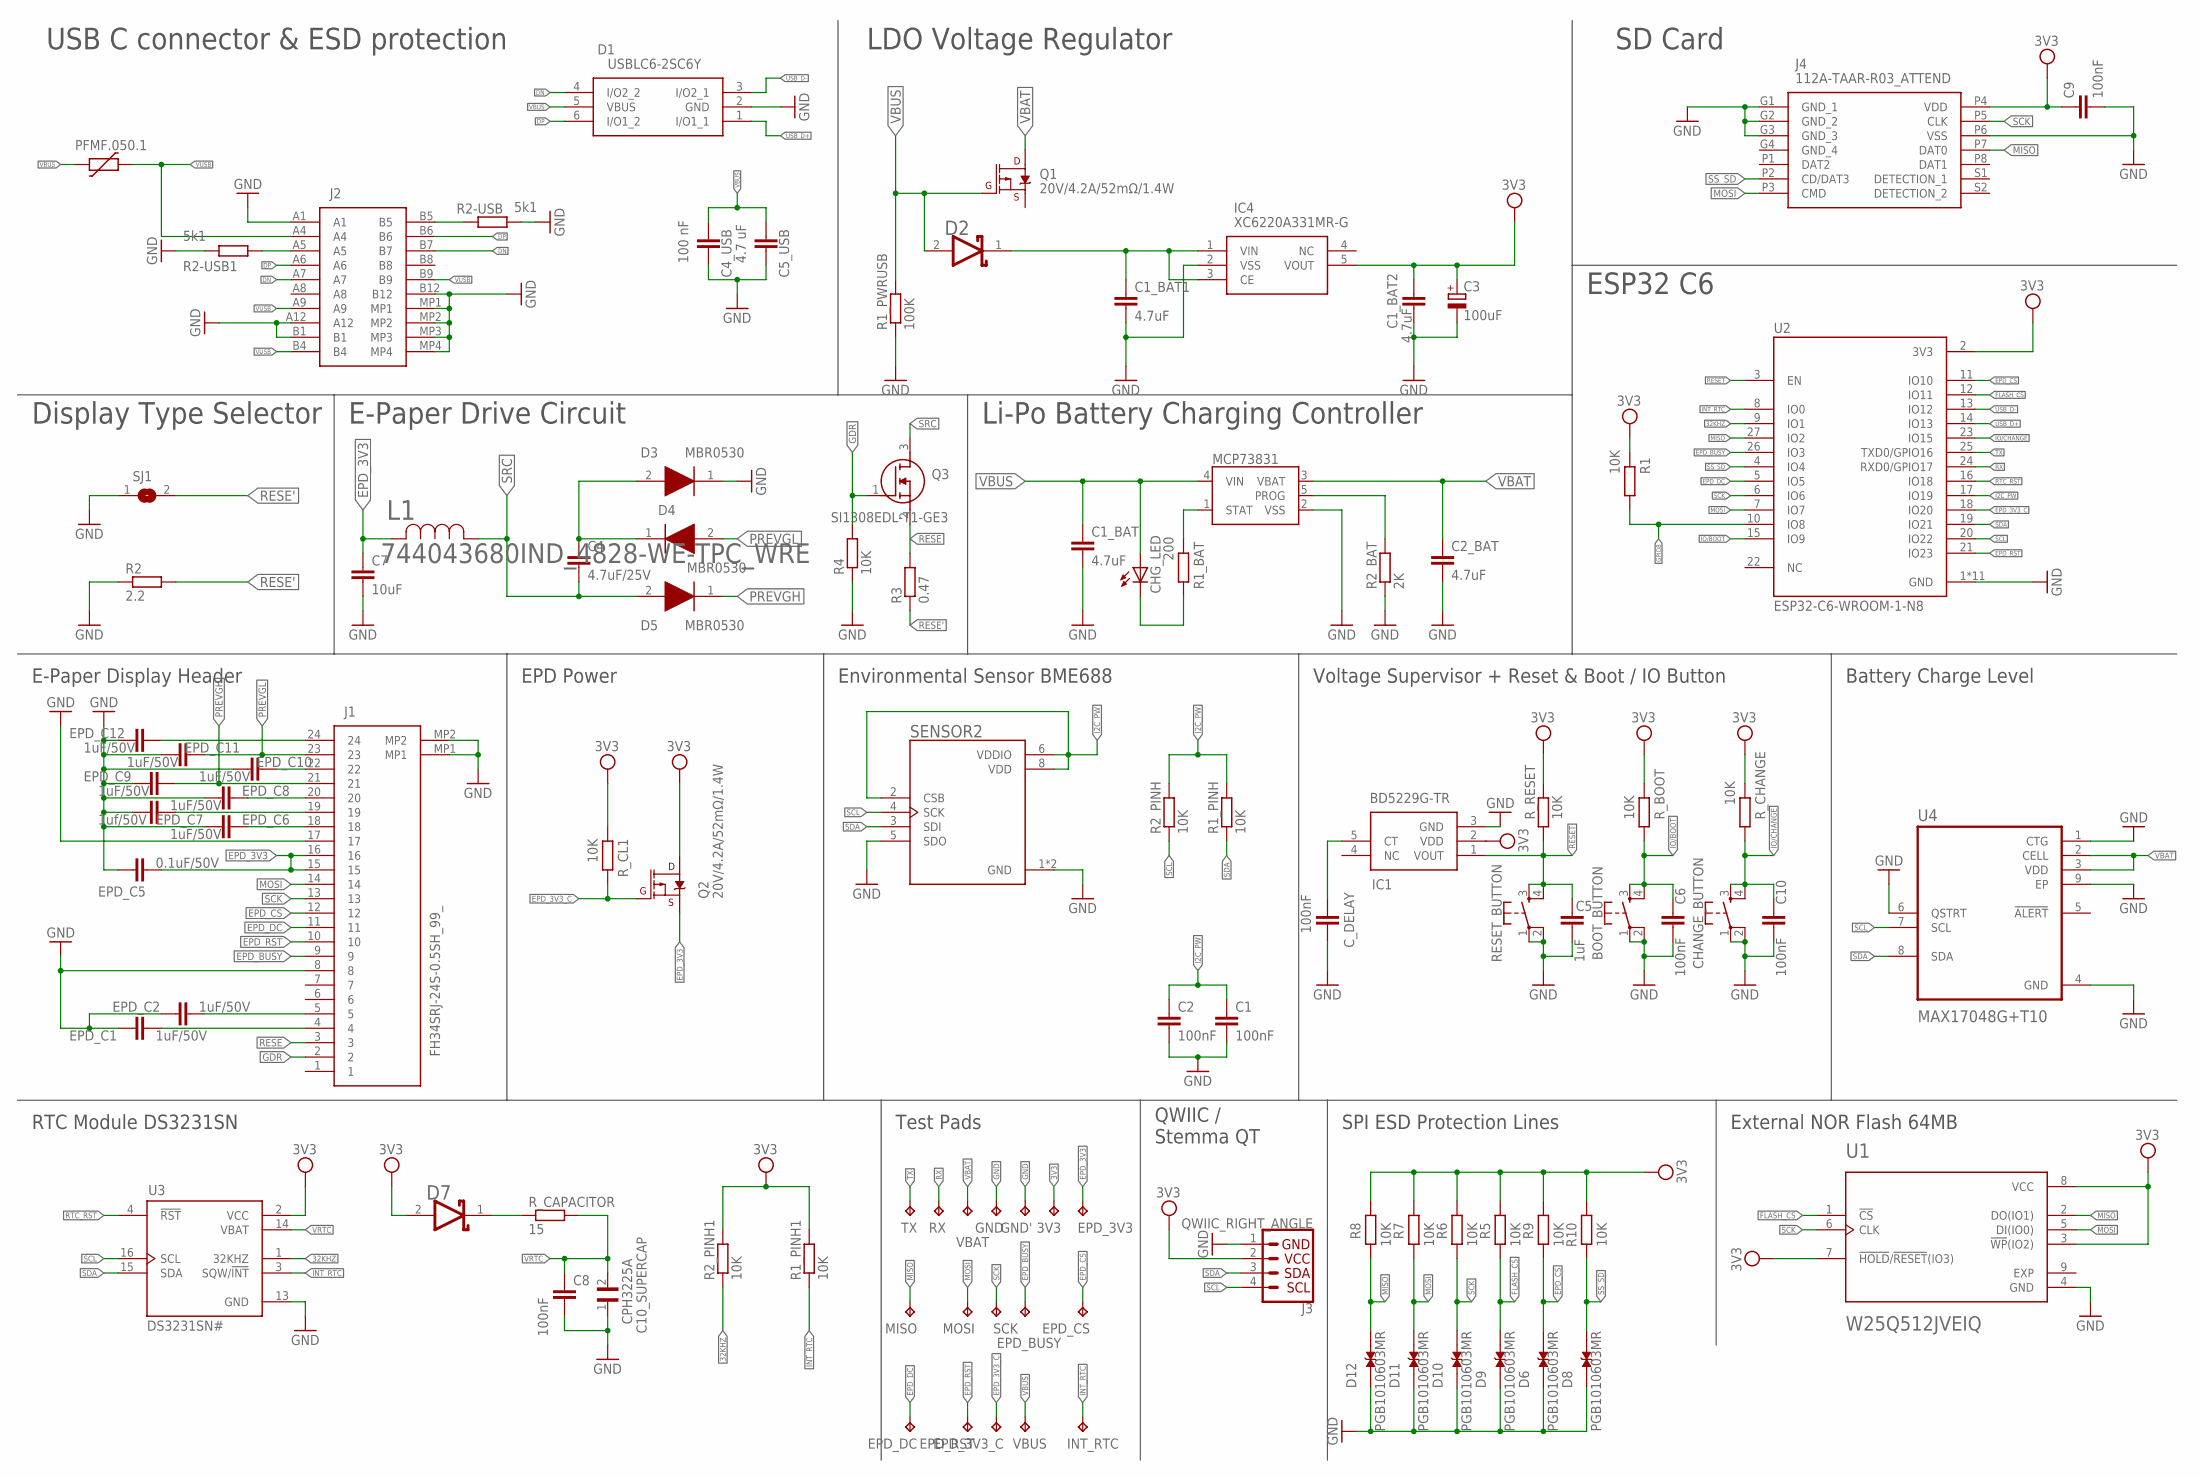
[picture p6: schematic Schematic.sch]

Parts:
3V3: TPTP20R; TP20R
BOOT_BUTTON: BUTTON_CUSYOMV1PACKAGE; MYBUTTON
C1, C2, C6, C8, C9, C10: 100nF; EAGLE-LTSPICE_C0402
C1_BAT, C1_BAT1, C1_BAT2, C2_BAT: 4.7uF; EAGLE-LTSPICE_C0402
C3: 100uF; RCL_CT3528
C4: 4.7uF/25V; EAGLE-LTSPICE_C0402
C4_USB: 100 nF; EAGLE-LTSPICE_C0402
C5: 1uF; EAGLE-LTSPICE_C0402
C5_USB: 4.7 uF; EAGLE-LTSPICE_C0402
C7: 10uF; EAGLE-LTSPICE_C0402
C10_SUPERCAP: CPH3225A; CAPCP3225X100N
CHANGE_BUTTON: BUTTON_CUSYOMV1PACKAGE; MYBUTTON
CHG_LED: ADAFRUIT_LEDCHIP-LED0603; ADAFRUIT_CHIP-LED0603
C_DELAY: 100nF; EAGLE-LTSPICE_C0402
D1: USBLC6-2SC6Y; SOT95P280X145-6N
D2, D7: ESP32_WROVER_AVX---SD0805S020S1R0_AVX_SD0805S020S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; ESP32_WROVER_AVX---SD0805S020S1R0_AVX_SD0805S020S1R0_0
D3, D4, D5: MBR0530; SOD3716X135N
D6, D8, D9, D10, D11, D12: PGB1010603MR; DIOC1608X36N
EPD_3V3, EPD_3V3_C: TPTP20R; TP20R
EPD_BUSY: TPTP20R; TP20R
EPD_C1, EPD_C2, EPD_C6, EPD_C8, EPD_C9, EPD_C10, EPD_C11, EPD_C12: 1uF/50V; EAGLE-LTSPICE_C0402
EPD_C5: 0.1uF/50V; EAGLE-LTSPICE_C0402
EPD_C7: 1uf/50V; EAGLE-LTSPICE_C0402
EPD_CS: TPTP20R; TP20R
EPD_DC: TPTP20R; TP20R
EPD_RST: TPTP20R; TP20R
GND: TPTP20R; TP20R
GND': TPTP20R; TP20R
IC1: BD5229G-TR; SOT95P280X125-5N
IC4: XC6220A331MR-G; SOT95P280X120-5N
INT_RTC: TPTP20R; TP20R
J1: FH34SRJ-24S-0.5SH_99_; FH34SRJ24S05SH99
J2: SAMACSYS_PARTS_USB4110-GF-A; SAMACSYS_PARTS_USB4110GFA
J3: QWIIC_RIGHT_ANGLE; JST04_1MM_RA
J4: 112A-TAAR-R03_ATTEND; 112ATAARR03ATTEND
L1: 744043680IND_4828-WE-TPC_WRE; IND_4828-WE-TPC_WRE
MCP73831: ESP32_WROVER_SPARKFUN-IC-POWER_MCP73831; ESP32_WROVER_SPARKFUN-IC-POWER_SOT23-5
MISO: TPTP20R; TP20R
MOSI: TPTP20R; TP20R
PFMF.050.1: VARISTOR_3216; VARC3216X102N
Q1, Q2: 20V/4.2A/52mΩ/1.4W; ESP32_WROVER_SPARKFUN-DISCRETESEMI_SOT23-3
Q3: SI1308EDL-T1-GE3; SOT65P210X110-3N
R1, R1_PINH, R1_PINH1, R2_PINH, R2_PINH1, R4, R5, R6, R7, R8, R9, R10: 10K; ESP32_WROVER_EAGLE-LTSPICE_R0402
R1_BAT: 200; ESP32_WROVER_EAGLE-LTSPICE_R0402
R1_PWRUSB: 100K; ESP32_WROVER_EAGLE-LTSPICE_R0402
R2: 2.2; ESP32_WROVER_EAGLE-LTSPICE_R0402
R2-USB, R2-USB1: 5k1; ESP32_WROVER_EAGLE-LTSPICE_R0402
R2_BAT: 2K; ESP32_WROVER_EAGLE-LTSPICE_R0402
R3: 0.47; ESP32_WROVER_EAGLE-LTSPICE_R0402
RESET_BUTTON: BUTTON_CUSYOMV1PACKAGE; MYBUTTON
RX: TPTP20R; TP20R
R_BOOT: 10K; ESP32_WROVER_EAGLE-LTSPICE_R0402
R_CAPACITOR: 15; ESP32_WROVER_EAGLE-LTSPICE_R0402
R_CHANGE: 10K; ESP32_WROVER_EAGLE-LTSPICE_R0402
R_CL1: 10K; ESP32_WROVER_EAGLE-LTSPICE_R0402
R_RESET: 10K; ESP32_WROVER_EAGLE-LTSPICE_R0402
SCK: TPTP20R; TP20R
SENSOR2: ESP32_WROVER_BME680_BME680; ESP32_WROVER_BME680_PSON80P300X300X100-8N
SJ1: SJ
TX: TPTP20R; TP20R
U1: W25Q512JVEIQ; SON127P600X800X80-9N
U2: ESP32-C6-WROOM-1-N8; XCVR_ESP32-C6-WROOM-1-N8
U3: DS3231SN#; SOIC127P1032X265-16N
U4: MAX17048G+T10; SON50P200X200X80-9N
VBAT: TPTP20R; TP20R
VBUS: TPTP20R; TP20R

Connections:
3V3: 3V3.TP, C1_BAT2.1, C3.+, C9.1, D7.2 (ANODE), IC1.2 (VDD), IC4.5 (VOUT), J3.2, J4.P4 (VDD), Q2.3 (D), R1.2, R1_PINH1.2, R2_PINH1.2, R5.1, R6.1, R7.1, R8.1, R9.1, R10.1, R_BOOT.2, R_CHANGE.2, R_CL1.2, R_RESET.2, U1.3 (!WP!(IO2)), U1.7 (!HOLD!/!RESET!(IO3)), U1.8 (VCC), U2.2 (3V3), U3.2 (VCC)
32KHZ: R2_PINH1.1, U2.9 (IO1), U3.1 (32KHZ)
DN: D1.4 (I/O2_2), J2.A7, J2.B7
DP: D1.6 (I/O1_2), J2.A6, J2.B6
EPD_3V3: C7.1, EPD_3V3.TP, EPD_C5.1, J1.15, J1.16, L1.2, Q2.2 (S)
EPD_3V3_C: EPD_3V3_C.TP, Q2.1 (G), R_CL1.1, U2.18 (IO20)
EPD_BUSY: EPD_BUSY.TP, J1.9, U2.26 (IO3)
EPD_CS: D6.2, EPD_CS.TP, J1.12, R9.2, U2.11 (IO10)
EPD_DC: EPD_DC.TP, J1.11, U2.5 (IO5)
EPD_RST: EPD_RST.TP, J1.10, U2.21 (IO23)
FLASH_CS: D9.2, R5.2, U1.1 (!CS), U2.12 (IO11)
GDR: J1.2, Q3.1 (G), R4.2
GND: BOOT_BUTTON.1, BOOT_BUTTON.2, C1.2, C1_BAT.2, C1_BAT1.2, C1_BAT2.2, C2.2, C2_BAT.2, C3.-, C4_USB.2, C5.2, C5_USB.2, C6.2, C7.2, C8.2, C9.2, C10.2, C10_SUPERCAP.1, CHANGE_BUTTON.1, CHANGE_BUTTON.2, C_DELAY.2, D1.2 (GND), D3.1 (K), D6.1, D8.1, D9.1, D10.1, D11.1, D12.1, EPD_C1.2, EPD_C2.2, EPD_C5.2, EPD_C6.2, EPD_C7.2, EPD_C8.2, EPD_C9.2, EPD_C10.2, EPD_C11.2, EPD_C12.2, GND.TP, GND'.TP, IC1.3 (GND), IC4.2 (VSS), J1.8, J1.17, J1.MP1, J1.MP2, J2.A1, J2.A12, J2.B1, J2.B12, J2.MP1, J2.MP2, J2.MP3, J2.MP4, J3.1, J4.G1 (GND_1), J4.G2 (GND_2), J4.G3 (GND_3), J4.P6 (VSS), MCP73831.2 (VSS), R1_PWRUSB.1, R2.1, R2-USB.2, R2-USB1.1, R2_BAT.1, R4.1, RESET_BUTTON.1, RESET_BUTTON.2, SENSOR2.1 (GND), SENSOR2.5 (SDO), SENSOR2.7 (GND), SJ1.1, U1.4 (GND), U2.1 (GND), U2.28 (GND), U2.29_1 (GND), U2.29_2 (GND), U2.29_3 (GND), U2.29_4 (GND), U2.29_5 (GND), U2.29_6 (GND), U2.29_7 (GND), U2.29_8 (GND), U2.29_9 (GND), U3.13 (GND), U4.1 (CTG), U4.4 (GND), U4.6 (QSTRT), U4.9 (EP)
GPIO8: R1.1, U2.10 (IO8)
I2C_PW: C1.1, C2.1, R1_PINH.2, R2_PINH.2, SENSOR2.2 (CSB), SENSOR2.6 (VDDIO), SENSOR2.8 (VDD), U2.17 (IO19)
INT_RTC: INT_RTC.TP, R1_PINH1.1, U2.8 (IO0), U3.3 (SQW/!INT)
IO/BOOT: BOOT_BUTTON.3, BOOT_BUTTON.4, C6.1, R_BOOT.1, U2.15 (IO9)
IO/CHANGE: C10.1, CHANGE_BUTTON.3, CHANGE_BUTTON.4, R_CHANGE.1, U2.23 (IO15)
MISO: D12.2, J4.P7 (DAT0), MISO.TP, R8.2, U1.2 (DO(IO1)), U2.27 (IO2)
MOSI: D11.2, J1.14, J4.P3 (CMD), MOSI.TP, R7.2, U1.5 (DI(IO0)), U2.7 (IO7)
unnamed: J2.A5, R2-USB1.2
unnamed: J2.B5, R2-USB.1
unnamed: MCP73831.5 (PROG), R2_BAT.2
unnamed: C1_BAT1.1, D2.1 (CATHODE), IC4.1 (VIN), IC4.3 (CE)
unnamed: EPD_C12.1, J1.24
unnamed: EPD_C6.1, J1.18
unnamed: MCP73831.1 (STAT), R1_BAT.2
unnamed: CHG_LED.C, R1_BAT.1
unnamed: C4.1, D3.2 (A), D4.1 (K)
unnamed: EPD_C7.1, J1.19
unnamed: EPD_C8.1, J1.20
unnamed: D7.1 (CATHODE), R_CAPACITOR.1
unnamed: EPD_C10.1, J1.22
unnamed: C_DELAY.1, IC1.5 (CT)
unnamed: EPD_C1.1, J1.4
unnamed: EPD_C2.1, J1.5
PREVGH: D5.1 (K), EPD_C9.1, J1.21
PREVGL: D4.2 (A), EPD_C11.1, J1.23
RESE: J1.3, Q3.2 (S), R3.2
RESE': R2.2, R3.1, SJ1.2
RESET: C5.1, IC1.1 (VOUT), RESET_BUTTON.3, RESET_BUTTON.4, R_RESET.1, U2.3 (EN)
RTC_RST: U2.16 (IO18), U3.4 (!RST)
RX: RX.TP, U2.24 (RXD0/GPIO17)
SCK: D10.2, J1.13, J4.P5 (CLK), R6.2, SCK.TP, U1.6 (CLK), U2.6 (IO6)
SCL: J3.4, R2_PINH.1, SENSOR2.4 (SCK), U2.20 (IO22), U3.16 (SCL), U4.7 (SCL)
SDA: J3.3, R1_PINH.1, SENSOR2.3 (SDI), U2.19 (IO21), U3.15 (SDA), U4.8 (SDA)
SRC: C4.2, D5.2 (A), L1.1, Q3.3 (D)
SS_SD: D8.2, J4.P2 (CD/DAT3), R10.2, U2.4 (IO4)
TX: TX.TP, U2.25 (TXD0/GPIO16)
USB_D+: D1.1 (I/O1_1), U2.14 (IO13)
USB_D-: D1.3 (I/O2_1), U2.13 (IO12)
VBAT: C2_BAT.1, MCP73831.3 (VBAT), Q1.3 (D), U4.2 (CELL), U4.3 (VDD), VBAT.TP
VBUS: C1_BAT.1, C4_USB.1, C5_USB.1, CHG_LED.A, D1.5 (VBUS), D2.2 (ANODE), MCP73831.4 (VIN), PFMF.050.1.1, Q1.1 (G), R1_PWRUSB.2, VBUS.TP
VRTC: C8.1, C10_SUPERCAP.2, R_CAPACITOR.2, U3.14 (VBAT)
VUSB: J2.A4, J2.A9, J2.B4, J2.B9, PFMF.050.1.2

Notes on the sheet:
USB C connector & ESD protection
LDO Voltage Regulator
SD Card
ESP32 C6
Display Type Selector
E-Paper Drive Circuit
Li-Po Battery Charging Controller
E-Paper Display Header
EPD Power
Environmental Sensor BME688
Voltage Supervisor + Reset & Boot / IO Button
Battery Charge Level
RTC Module DS3231SN
Test Pads
QWIIC / Stemma QT
SPI ESD Protection Lines
External NOR Flash 64MB

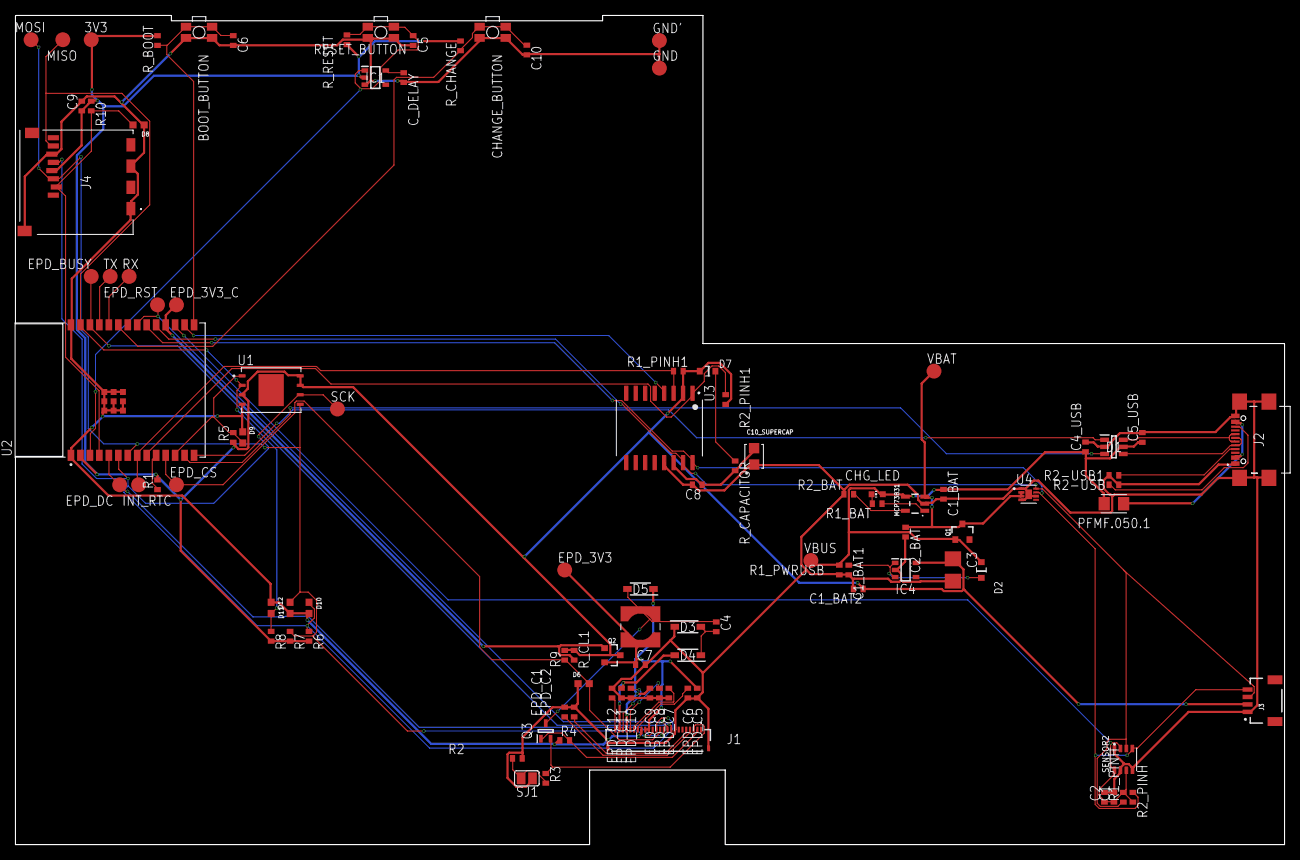
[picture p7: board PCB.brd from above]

Board: 2 copper layers, 170.2 x 111.2 mm, 103 parts (0 on the bottom side), 55 nets.

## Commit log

2025-04-06 Done without README
    [BOM.csv, PCB.brd, PnP.csv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]
2025-04-06 Started README
    [BOM.csv]
2025-04-06 Added descriptions and BOM to README
2025-04-15 Solved Issues
    [PCB.brd, Schematic.sch]

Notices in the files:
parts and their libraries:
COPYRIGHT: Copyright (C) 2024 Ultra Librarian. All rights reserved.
